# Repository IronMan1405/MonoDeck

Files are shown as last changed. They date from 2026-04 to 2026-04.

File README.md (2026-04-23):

# MonoDeck v2

A compact, handheld game console built around the Raspberry Pi Pico 2 W, featuring a 128×64 OLED display and a custom game engine with a registry-based architecture.

---

## Games

| Game | Description |
|---|---|
| Snake | Classic snake |
| Pong | One-paddle pong |
| Breakout | Block-breaking arcade game |
| Tetricore | Tetris-style falling block game |
| Flappy | Flappy bird style arcade runner game |
| Conway's Game of Life | A zero Player game (find out if you don't know ) |
| Mines | Minesweeper |
---

## Hardware

### Bill of Materials

| Component | Details |
|---|---|
| Microcontroller | Raspberry Pi Pico 2 W |
| Display | SH110x 128×64 OLED (I2C) |
| PCB | Custom PCB |
| Prototyping | Breadboard |
| Enclosure | 3D printed case |
| Power | Li-Po battery |

### Wiring

The display communicates over I2C. Default pin configuration is defined in `platform/platform_config.h`.
| Component Pin | Pico GPIO | 
|---|---|
| OLED SDA | GPIO 8 |
| OLED SCL | GPIO 9 |
| Up Button | GPIO 11 |
| Down Button | GPIO 12 |
| Left Button | GPIO 13 |
| Right Button | GPIO 10 |
| A Button | GPIO 20 |
| B Button | GPIO 21 |
| SEL Button | GPIO 3 |
| START Button | GPIO 2 |

---

## Project Structure

```
MonoDeck_v2/
├── MonoDeck_v2.c          # Entry point / main loop
├── app_registry/
│   ├── app_registry.h     # Game struct definition, extern declarations
│   └── app_registry.c     # Game registry table — only file to edit when adding a game
├── core/
│   ├── app_state.h/.c     # AppState enum (BOOT, MENU, IN_GAME)
│   ├── engine.h/.c        # launchGame, tickGame, requestExitToMenu
│   ├── input.h/.c         # Button input handling
│   └── boot.h/.c          # Boot sequence
├── menu/
│   └── menu.h/.c          # Scrollable game menu
├── games/
│   ├── snake/
│   ├── pong/
│   ├── breakout/
│   └── tetricore/
├── drivers/
│   ├── sh110x/            # OLED display driver
│   └── buttons/           # button interface
├── platform/
│   ├── platform_config.h  # Pin definitions, I2C config
│   ├── platform_init.h/.c # Hardware initialisation
│   └── platform_time.h/.c # Timing utilities
├── hardware/
│   ├── pcb/
│   │   └── monodeck/
│   │       ├── *.kicad_pro
│   │       ├── *.kicad_sch
│   │       ├── *.kicad_pcb
│   │       └── (other KiCad files)
│   └── cad/
└── assets/                # Bitmaps, fonts
```

---

## Build Instructions

### Prerequisites

- [Raspberry Pi Pico SDK v2.2.0](https://github.com/raspberrypi/pico-sdk)
- CMake ≥ 3.13
- ARM GCC toolchain `14_2_Rel1` (`arm-none-eabi-gcc`)
- [picotool v2.2.0](https://github.com/raspberrypi/picotool)

The easiest way to get all of these is via the [Raspberry Pi Pico VS Code Extension](https://marketplace.visualstudio.com/items?itemName=raspberry-pi.raspberry-pi-pico), which installs the SDK, toolchain, and picotool automatically under `~/.pico-sdk/`.

### Build

```bash
git clone https://github.com/IronMan1405/MonoDeck_v2
cd MonoDeck_v2
mkdir build && cd build
cmake ..
make
```

This produces `MonoDeck_v2.uf2` in the `build/` directory.

> **Note:** The CMakeLists is configured for `pico2_w`. If you are using a standard Pico W, change `set(PICO_BOARD pico2_w ...)` to `set(PICO_BOARD pico_w ...)` before building.

### Flash

**Option A — VS Code (recommended)**
 
If you're using the Raspberry Pi Pico VS Code Extension:
 
1. Open the project in VS Code
2. Click the **Run** button in the Pico sidebar (or use `Ctrl+Shift+P` → `Raspberry Pi Pico: Run Project`)
3. The extension builds, flashes, and reboots the device automatically via picotool — no manual BOOTSEL needed
 
**Option B — Manual UF2**

1. Hold the **BOOTSEL** button on the Pico W and connect via USB
2. It mounts as a mass storage device
3. Copy `MonoDeck_v2.uf2` onto it — it will reboot automatically

---

## Adding a New Game

The registry architecture means adding a game requires changes to **one file only**.

### 1. Create your game files

```
games/
└── mygame/
    ├── mygame.h
    └── mygame.c
```

Your game must expose three functions:

```c
void initMyGame(void);
void updateMyGame(void);
void drawMyGame(void);
```

To exit back to the menu from within a game, call:

```c
#include "core/engine.h"

requestExitToMenu();
```

### 2. Register the game

Open `app_registry/app_registry.c` and add one `#include` and one entry:

```c
#include "games/mygame/mygame.h"   // add this

Game games[] = {
    {"Snake",     initSnake,     updateSnake,     drawSnake},
    {"Pong",      initPong,      updatePong,      drawPong},
    {"Breakout",  initBreakout,  updateBreakout,  drawBreakout},
    {"Tetricore", initTetricore, updateTetricore, drawTetricore},
    {"MyGame",    initMyGame,    updateMyGame,    drawMyGame},  // add this
};
```

### 3. Add highscore storage for the game

Open `platform/storage_map.h` and add the entry:

```c
typedef struct {
    uint32_t magic;
    uint16_t snake_hs;
    uint16_t pong_hs;
    uint16_t breakout_hs;
    uint16_t tetricore_hs;
    uint16_t mygame_hs;    // add this
    uint8_t  _pad[256 - 12];
} StoragePage;

// add this, make sure to keep the offset of the new game by 2 from the previous game
#define STORAGE_MYGAME_HIGHSCORE_OFFSET 0x008
```

Next open `platform/platform_storage.c` in the definition of ```loadStorage()``` add:

```c
void loadStorage(void) {
    ...

    if (page.magic == STORAGE_MAGIC) {
        gStorage = page;
    } else {
        gStorage.magic = STORAGE_MAGIC;
        gStorage.snake_hs = 0;
        gStorage.pong_hs = 0;
        gStorage.breakout_hs = 0;
        gStorage.tetricore_hs = 0;
        gStorage.mygame_hs = 0;     // add this
    }
}
```

And initialize it in your game's init function in `games/mygame/mygame.c`:

```c
#include "platform/platform_storage.h"

void initMyGame(void) {
    ...

    loadStorage();
    highScore = gStorage.mygame_hs;

    if (highScore < 0 || highScore > 999) highScore = 0;

    ...
}
```

*(Note: you can set the upper limit of highscore to anything, i have set it as 999 for most games, and 99999 for tetricore)*

---

## ToDo

- [x] Add Select & Start buttons interface
- [x] Add persistent high score storing
- [x] Refine Scoring methods
- [ ] Add levels & game modes
- [x] Add PCB files 
- [x] Add enclosure CAD files 
- [x] Implement Bi-directional rotation & wall kicks in Tetricore
- [x] UI/UX enhancements
- [x] Fix reverse scroll

---

## License

MIT

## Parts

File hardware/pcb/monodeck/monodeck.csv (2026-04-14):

Id | Designator | Footprint | Quantity | Designation | Supplier and ref
1 | S5 | SW_SWT0211-050010GSA_REVA | 1 | B
2 | OLED1 | PinSocket_1x04_P2.54mm_Vertical | 1 | Conn_01x04_Socket
3 | S1 | SW_SWT0211-050010GSA_REVA | 1 | UP
4 | S8 | SW_SWT0211-050010GSA_REVA | 1 | START
5 | S7 | SW_SWT0211-050010GSA_REVA | 1 | SELECT
6 | S4 | SW_SWT0211-050010GSA_REVA | 1 | RIGHT
7 | S3 | SW_SWT0211-050010GSA_REVA | 1 | LEFT
8 | S2 | SW_SWT0211-050010GSA_REVA | 1 | DOWN
9 | S6 | SW_SWT0211-050010GSA_REVA | 1 | A
10 | U1 | TP4056-Module | 1 | TP4056
11 | PWR1 | SW_R1966ABLKBLKGR | 1 | R1966ABLKBLKGR
12 | BAT1 | JST_PH_B2B-PH-K_1x02_P2.00mm_Vertical | 1 | Conn_01x02
13 | J2,J1 | PinSocket_1x20_P2.54mm_Vertical | 2 | Conn_01x20_Socket

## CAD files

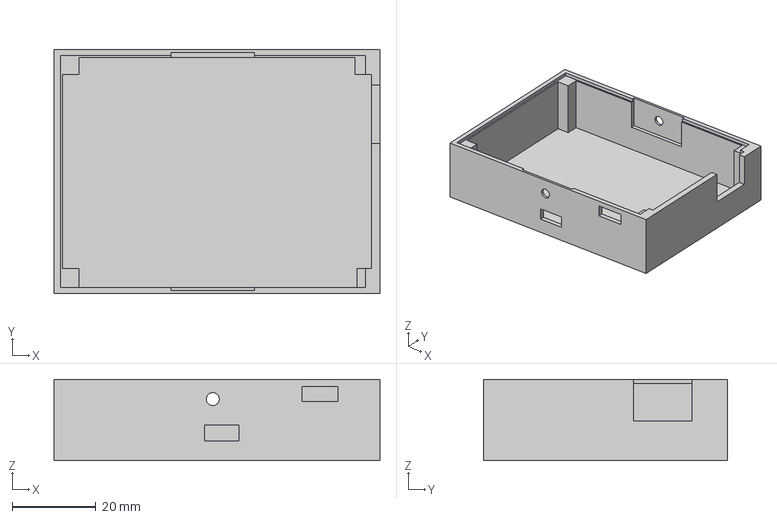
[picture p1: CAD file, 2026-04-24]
hardware/cad/case_bottom.step
78.0 x 58.5 x 19.5 mm

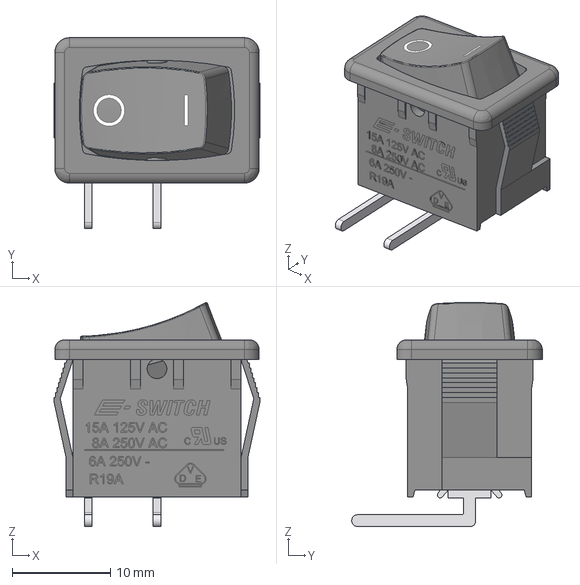
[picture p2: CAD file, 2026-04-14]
hardware/pcb/ProjectLibrary/R1966ABLKBLKGR/R1966ABLKBLKGR.step
20.9 x 19.4 x 22.8 mm

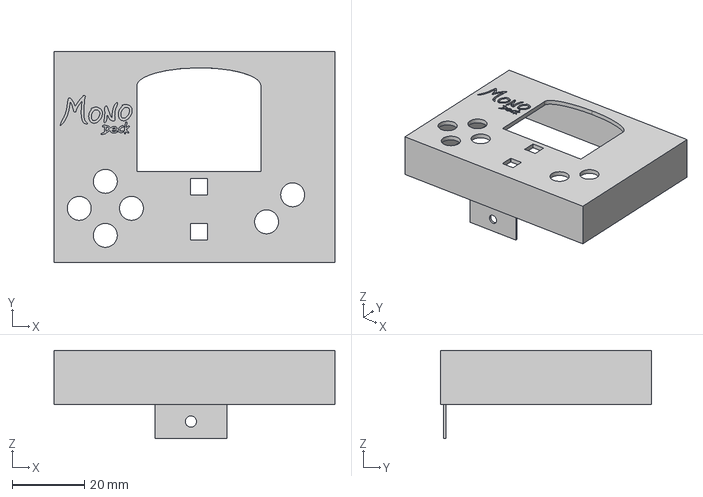
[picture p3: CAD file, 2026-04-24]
hardware/cad/case_top.step
78.0 x 58.5 x 24.5 mm

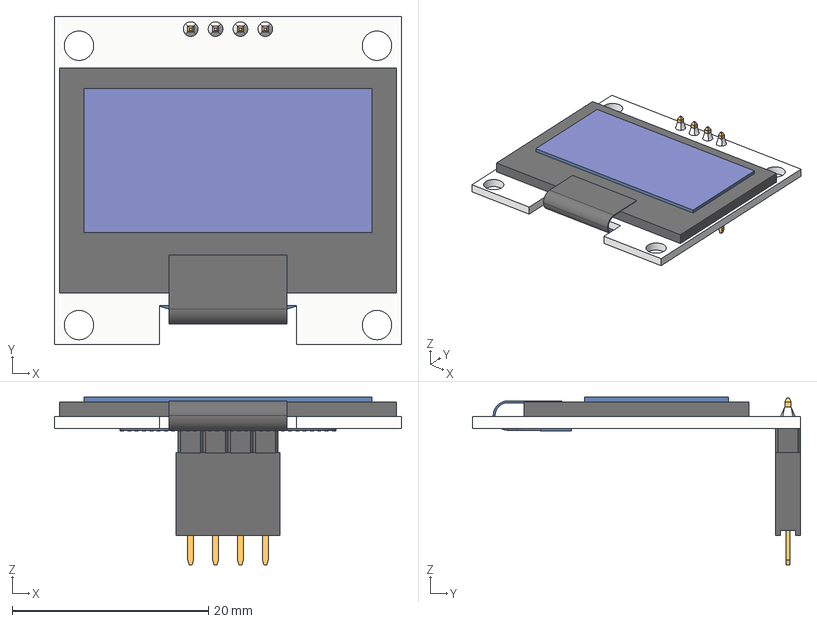
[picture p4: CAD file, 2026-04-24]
hardware/cad/PCB v8.step
35.4 x 33.5 x 17.1 mm
Board
PIN HEADER MALE 2.54MM P4
LCD
FLEX FILM
4 lü Lehim
PIN HEADER FAMALE 2.54MM P4

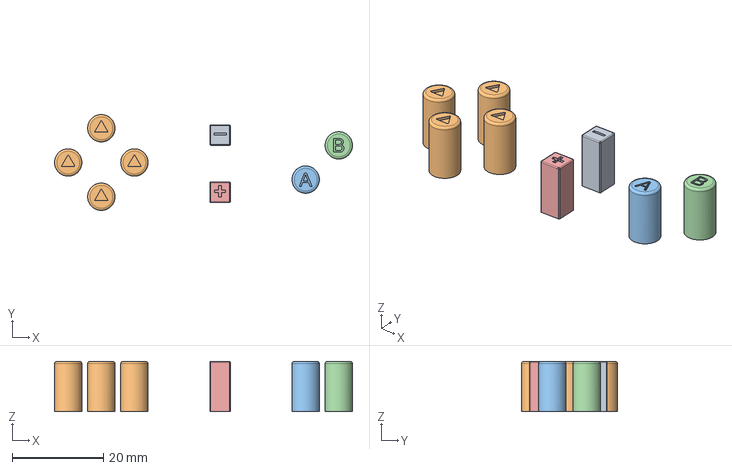
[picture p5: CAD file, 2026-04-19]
hardware/cad/buttons.step
65.2 x 21.0 x 11.0 mm

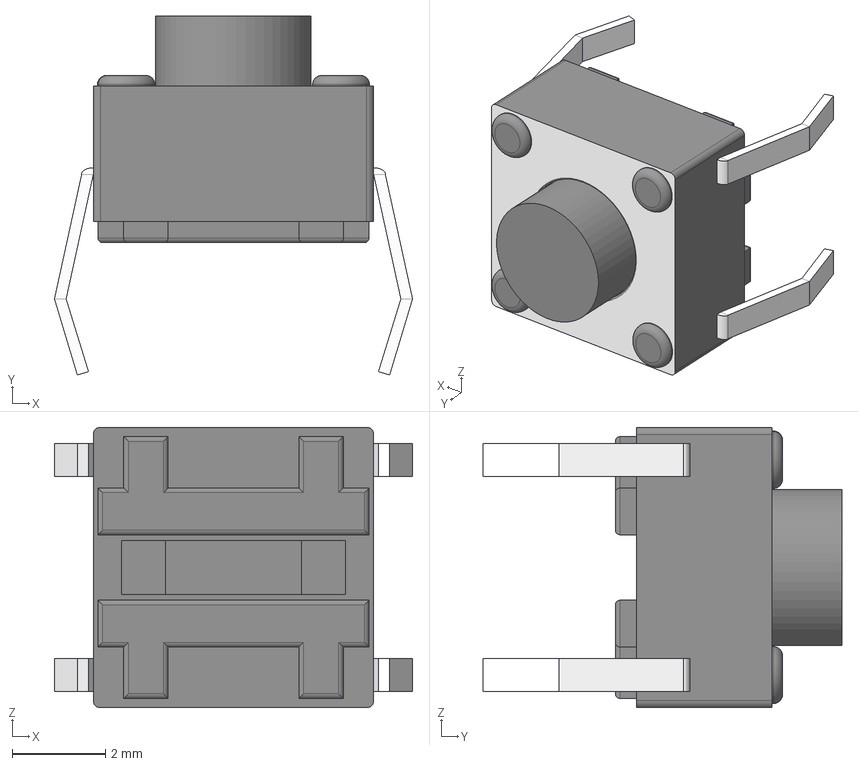
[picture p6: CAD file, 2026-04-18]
hardware/cad/push button.step
7.66 x 7.68 x 6.00 mm

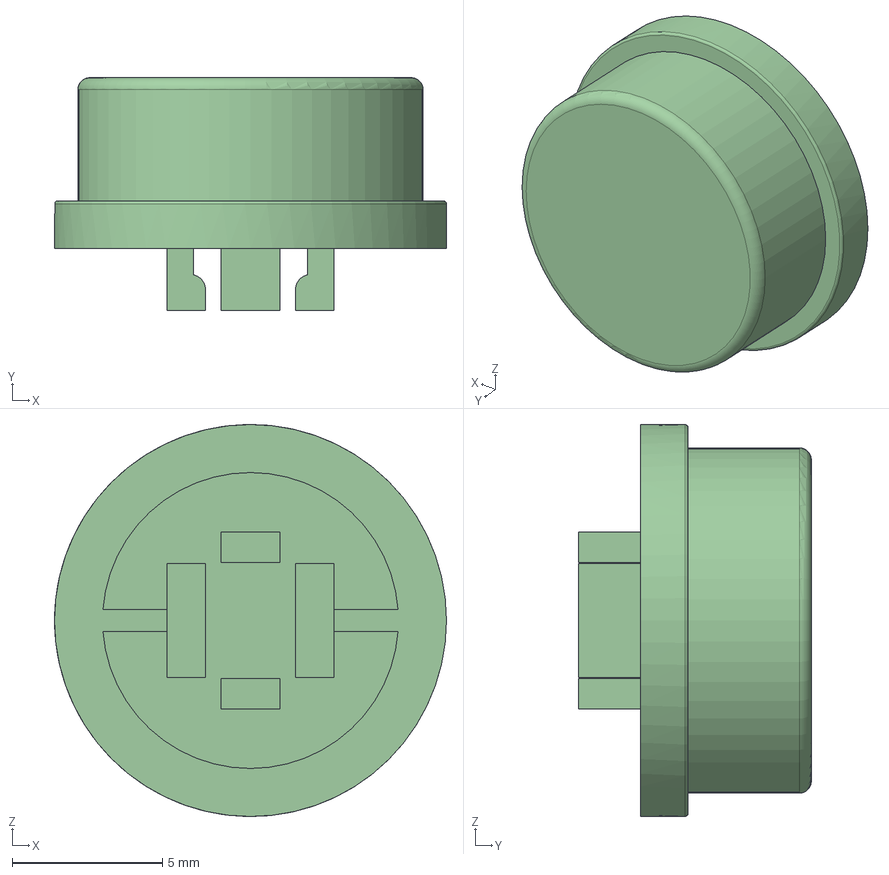
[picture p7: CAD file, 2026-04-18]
hardware/cad/Push_Button_Cap.step
13.1 x 7.75 x 13.1 mm

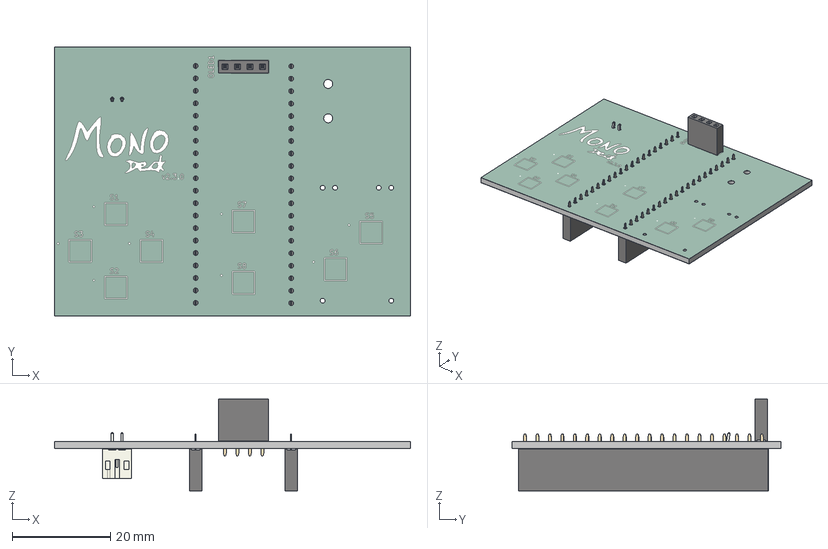
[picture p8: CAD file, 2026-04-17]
hardware/cad/monodeck_pcb.step
72.5 x 54.8 x 18.7 mm
PinSocket_1x04_P2.54mm_Vertical
JST_PH_B2B-PH-K_1x02_P2.00mm_Vertical
PinSocket_1x20_P2.54mm_Vertical x 2
monodeck_silkscreen
monodeck_soldermask
monodeck_PCB

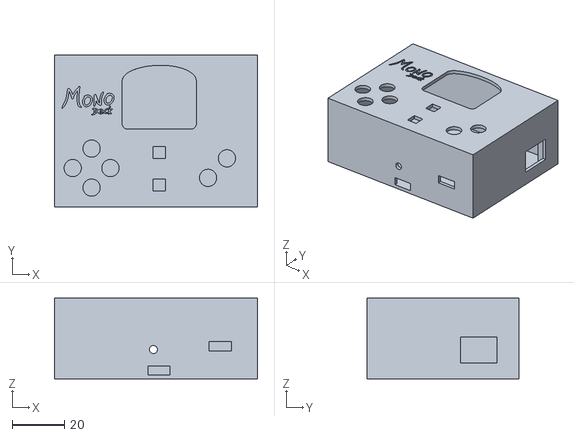
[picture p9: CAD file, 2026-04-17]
hardware/cad/monodeck_case.stl
78.0 x 58.5 x 31.0

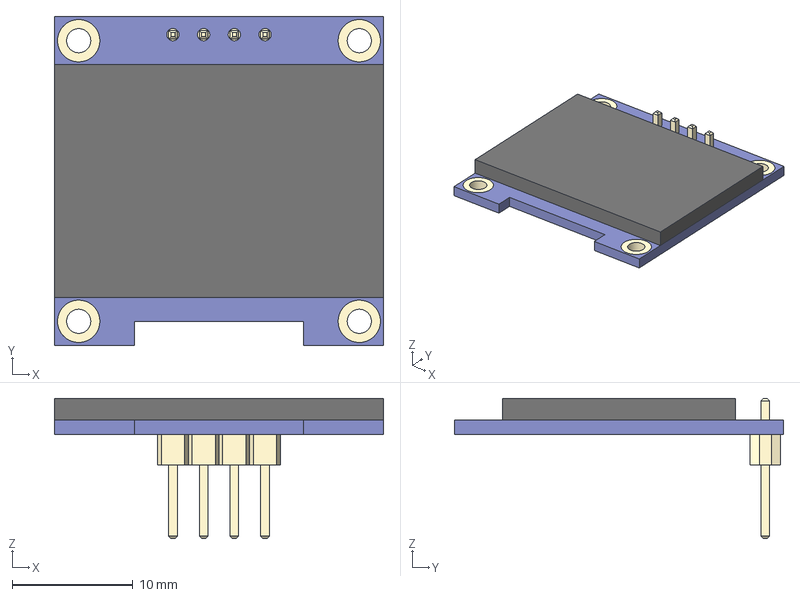
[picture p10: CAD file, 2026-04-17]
hardware/cad/LM096-128064 OLED DISPLAY .step
27.2 x 27.2 x 11.6 mm

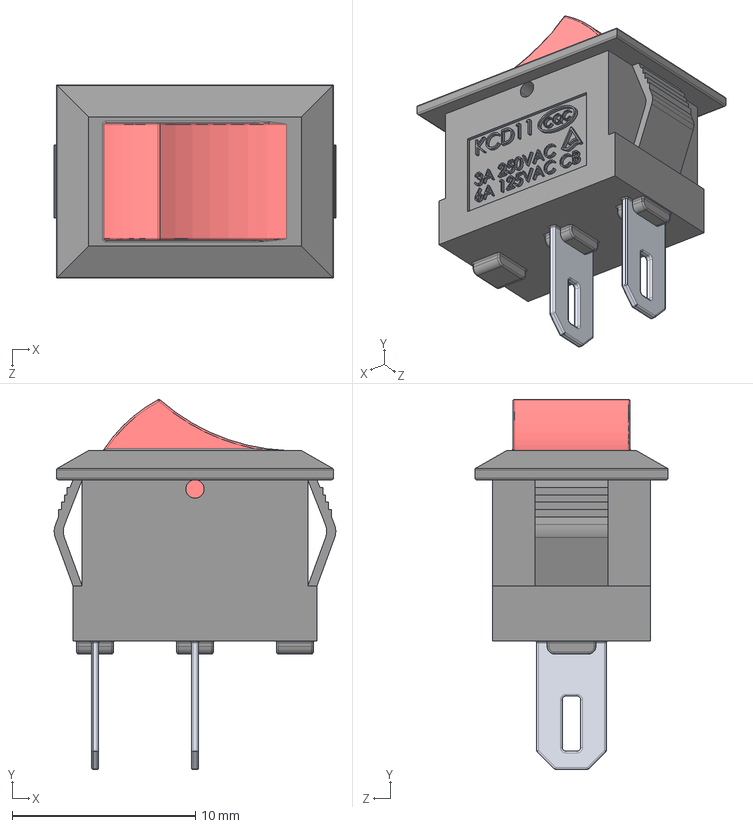
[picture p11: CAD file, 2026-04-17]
hardware/cad/Power Switch.STEP
15.4 x 20.2 x 10.6 mm

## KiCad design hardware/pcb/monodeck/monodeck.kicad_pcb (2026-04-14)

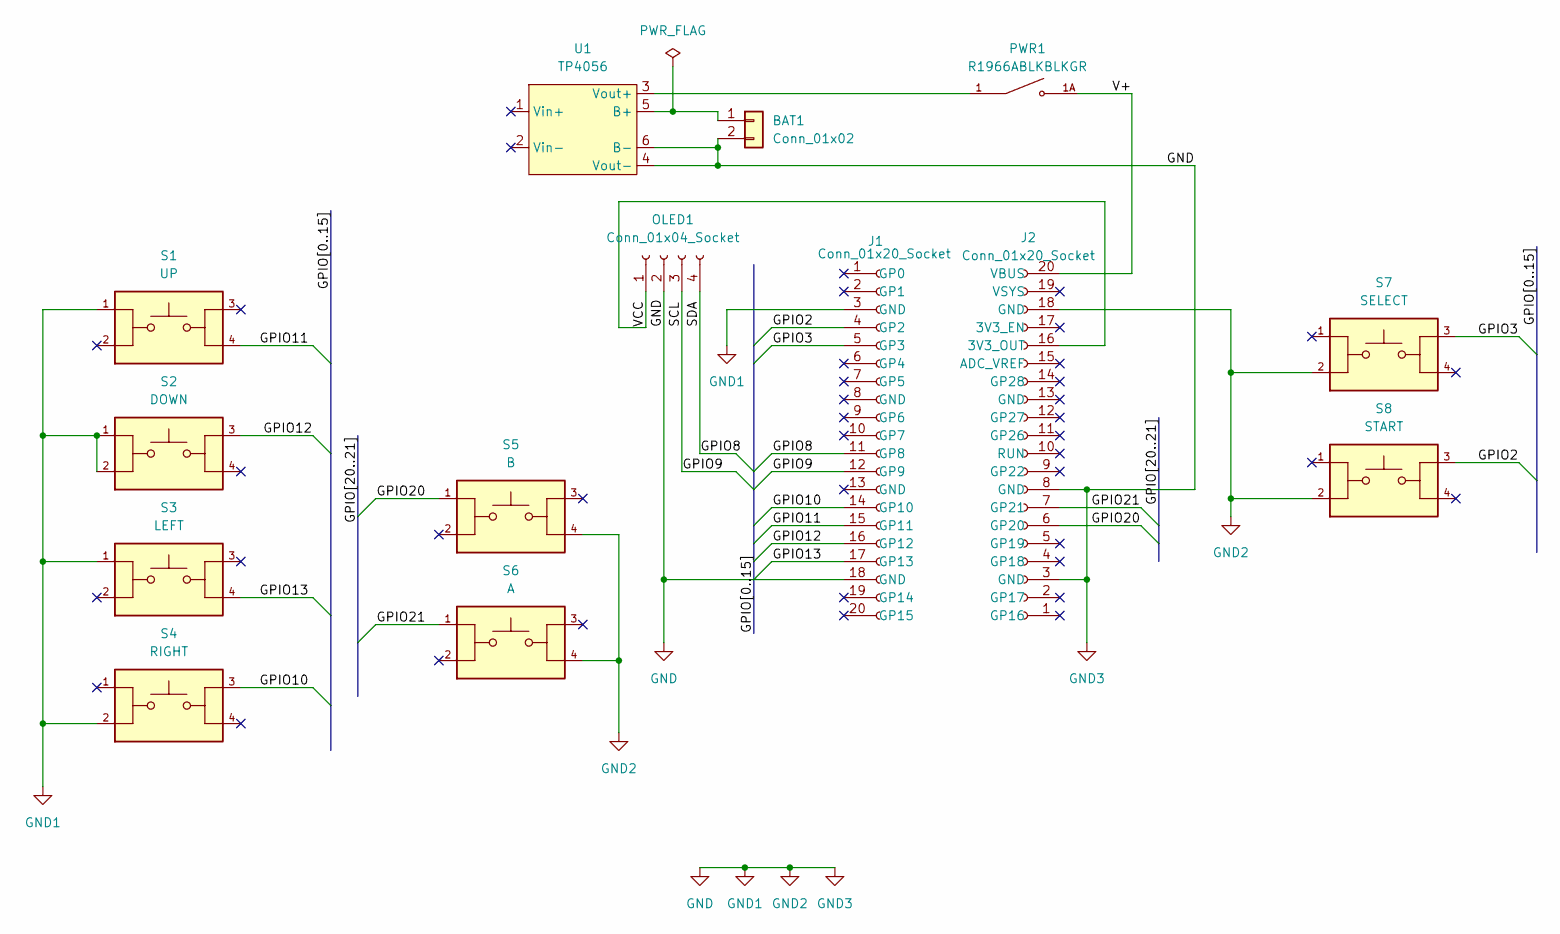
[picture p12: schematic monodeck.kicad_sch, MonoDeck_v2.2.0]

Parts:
BAT1: Conn_01x02; JST_PH_B2B-PH-K_1x02_P2.00mm_Vertical
J1, J2: Conn_01x20_Socket; PinSocket_1x20_P2.54mm_Vertical
OLED1: Conn_01x04_Socket; PinSocket_1x04_P2.54mm_Vertical
PWR1: R1966ABLKBLKGR; SW_R1966ABLKBLKGR; PARTREV E
S1: UP; SW_SWT0211-050010GSA_REVA; PARTREV A
S2: DOWN; SW_SWT0211-050010GSA_REVA; PARTREV A
S3: LEFT; SW_SWT0211-050010GSA_REVA; PARTREV A
S4: RIGHT; SW_SWT0211-050010GSA_REVA; PARTREV A
S5: B; SW_SWT0211-050010GSA_REVA; PARTREV A
S6: A; SW_SWT0211-050010GSA_REVA; PARTREV A
S7: SELECT; SW_SWT0211-050010GSA_REVA; PARTREV A
S8: START; SW_SWT0211-050010GSA_REVA; PARTREV A
U1: TP4056; TP4056-Module

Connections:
/GPIO2: J1.4 (GP2), S8.3
/GPIO3: J1.5 (GP3), S7.3
/GPIO8: J1.11 (GP8), OLED1.4
/GPIO9: J1.12 (GP9), OLED1.3
/GPIO10: J1.14 (GP10), S4.3
/GPIO11: J1.15 (GP11), S1.4
/GPIO12: J1.16 (GP12), S2.3
/GPIO13: J1.17 (GP13), S3.4
/GPIO20: J2.6 (GP20), S5.1
/GPIO21: J2.7 (GP21), S6.1
/V+: J2.20 (VBUS), PWR1.1A
/VCC: J2.16 (3V3_OUT), OLED1.1
GND: BAT1.2, J1.3 (GND), J1.18 (GND), J2.3 (GND), J2.8 (GND), J2.18 (GND), OLED1.2, S1.1, S2.1, S2.2, S3.1, S4.2, S5.4, S6.4, S7.2, S8.2, U1.4 (Vout-), U1.6 (B-)
unnamed: BAT1.1, U1.5 (B+)
unnamed: PWR1.1, U1.3 (Vout+)

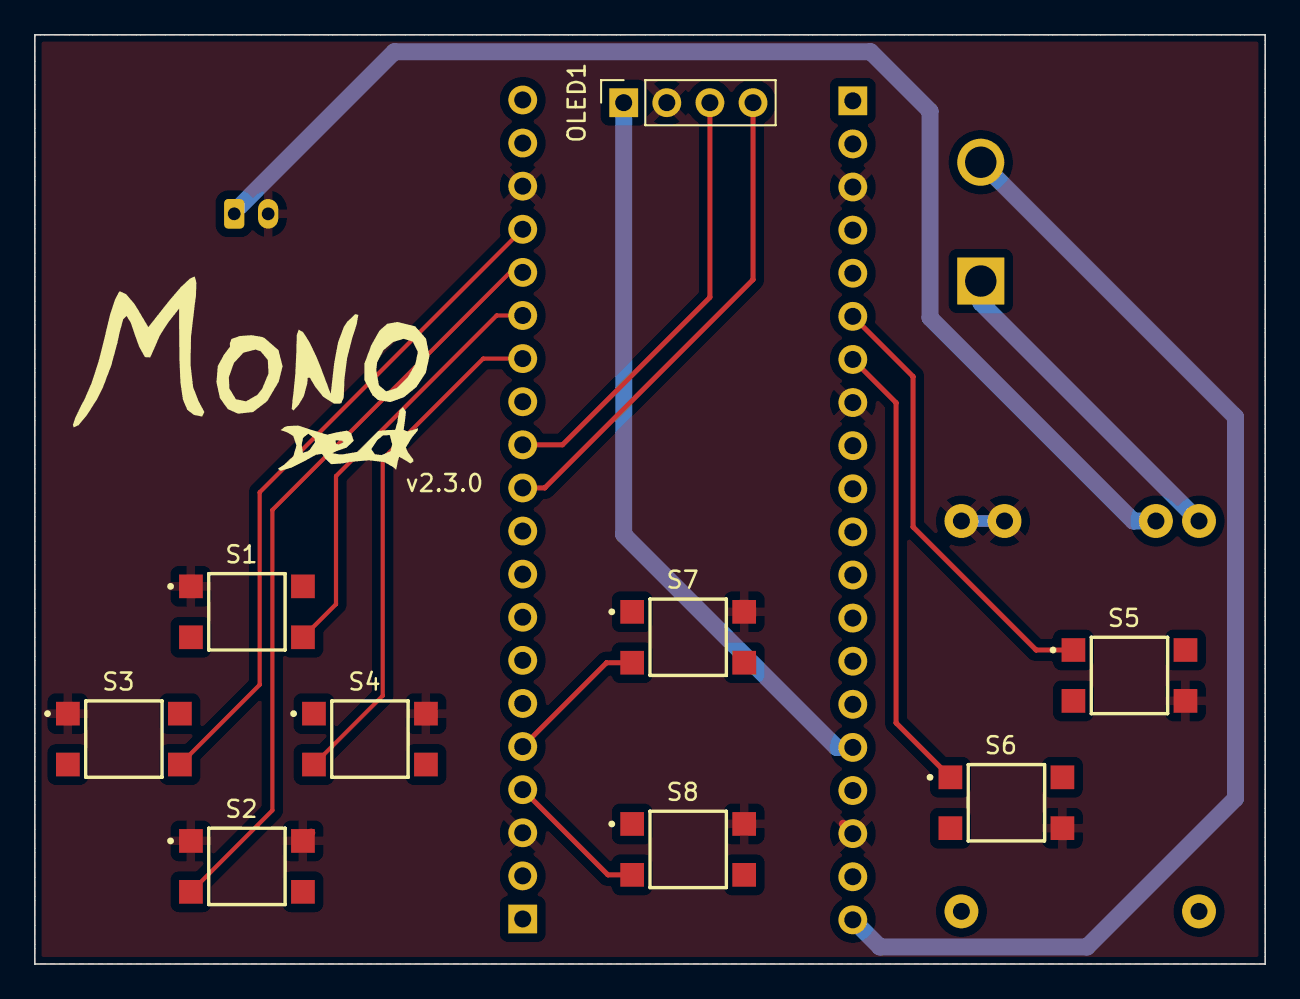
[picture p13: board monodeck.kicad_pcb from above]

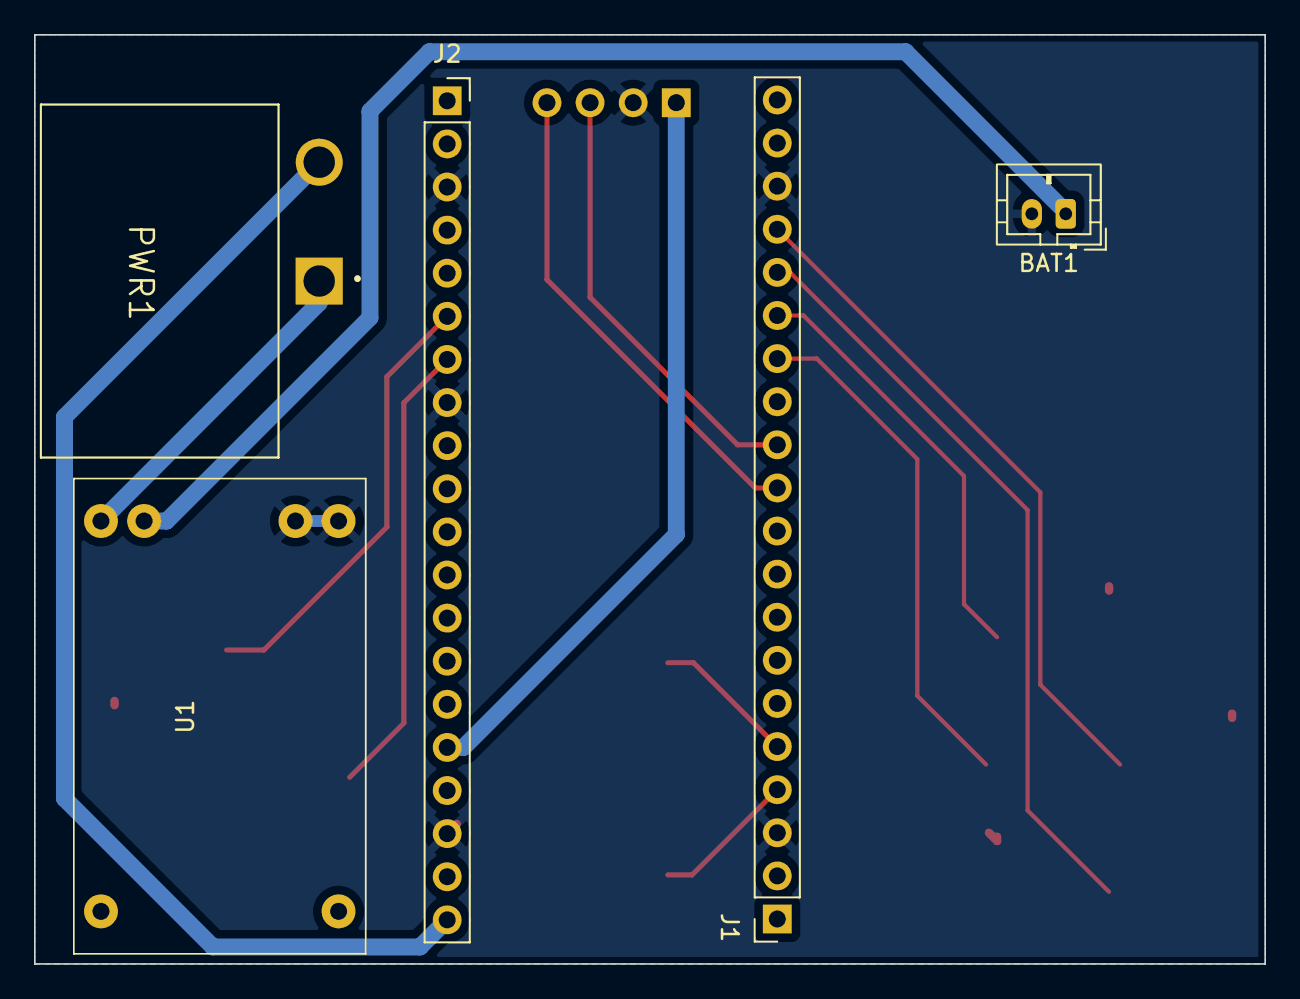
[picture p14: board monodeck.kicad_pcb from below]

Board: 2 copper layers, 72.5 x 54.8 mm, 14 parts (5 on the bottom side), 15 nets.

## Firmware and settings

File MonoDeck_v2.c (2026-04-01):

#include <stdio.h>
#include "pico/stdlib.h"
#include "hardware/i2c.h"

#include "platform/platform_config.h"
#include "platform/platform_init.h"
#include "platform/platform_time.h"

#include "drivers/sh110x/sh110x.h"

#include "core/app_state.h"
#include "app_registry/app_registry.h"
#include "core/input.h"
#include "core/engine.h"
#include "core/boot.h"

#include "menu/menu.h"

int main() {
    platform_init();

    sleep_ms(5000);

    printf("Monodeck v2 booting...\n");

    uint8_t dummy = 0x00;
    int ret = i2c_write_blocking(I2C_PORT, DISPLAY_I2C_ADDRESS, &dummy, 1, false);

    if (ret < 0) {
        printf("OLED NOT responding on I2C\n");
    } else {
        printf("OLED ACKed on I2C\n");
    }
    
    sh110x_init();
    sh110x_clear();
    sh110x_update();

    initInput();
    initBoot();

    while (1) {
        if (!platform_frame_ready()) continue;

        updateInput();

        switch (currentState) {
        case BOOT:
            updateBoot();
            drawBoot();
            break;
        case MENU:
            updateMenu();
            drawMenu();
            break;
        case IN_GAME:
            tickGame();
            break;
        }

        if (gameWantsExit) {
            gameWantsExit = false;
            // requestExitToMenu();
            initMenu();
            currentState = MENU;
        }
    }

    return 0;
}

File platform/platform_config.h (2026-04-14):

#pragma once

#define I2C_PORT i2c0
#define I2C_SDA_PIN 8
#define I2C_SCL_PIN 9
#define I2C_BAUDRATE 400000
#define DISPLAY_I2C_ADDRESS 0x3c

#define BTN_UP_PIN 11
#define BTN_DOWN_PIN 12
#define BTN_LEFT_PIN 13
#define BTN_RIGHT_PIN 10
#define BTN_A_PIN 20
#define BTN_B_PIN 21
#define BTN_SEL_PIN 3
#define BTN_START_PIN 2

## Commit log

2026-01-21 Monodecl v1.0 — Arduino/PlatformIO final
2026-01-21 Monodecl v1.0 — ESP8266/PlatformIO final
2026-01-21 Initialize MonoDeck_v2 Pico
2026-01-21 Initialize Monodeck v2 Pico SDK project
2026-01-21 initialize and test pico
2026-02-15 completed oled driver
2026-02-19 fixed button read, added monodeck logos
    [MonoDeck_v2.c, sh110x.c]
2026-03-31 fixed exit game bug
    [MonoDeck_v2.c]
2026-03-31 fix: display edge warp bug, game exit bug
    [MonoDeck_v2.c, sh110x.c]
2026-04-01 added select and start button interface in snake
2026-04-01 added select & start button interface
2026-04-02 refined breakout physics, fixed highscore clamp for all games
2026-04-14 add PCB design for MonoDeck v2.2.0
    [R1966ABLKBLKGR.step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]
2026-04-17 Enclosure cad v1.1 (#3)
    Cad for enclosure of monodeck is finalised for the upcoming version.
    [LM096-128064 OLED DISPLAY .step, Power Switch.STEP, case_bottom.step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]
2026-04-18 added buttons cad (forgot last time)
    [Push_Button_Cap.step, buttons.step, case_bottom.step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]
2026-04-19 updated buttons cad, added deboss
    [buttons.step]
2026-04-24 modified screen window and bottom internal clearance (#4)
    [PCB v8.step, case_bottom.step, case_top.step]
